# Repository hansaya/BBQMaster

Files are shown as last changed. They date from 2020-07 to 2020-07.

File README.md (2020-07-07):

# BBQMaster
8 channel temperature monitor for barbecuing.

# Features
* 4 NTC thermistor channels.
* 4 K-type thermocouple channels.
* Web interface to monitor the temperatures.
* MQTT support with hassio auto discovery.
* OTA updates.
* Web portal.
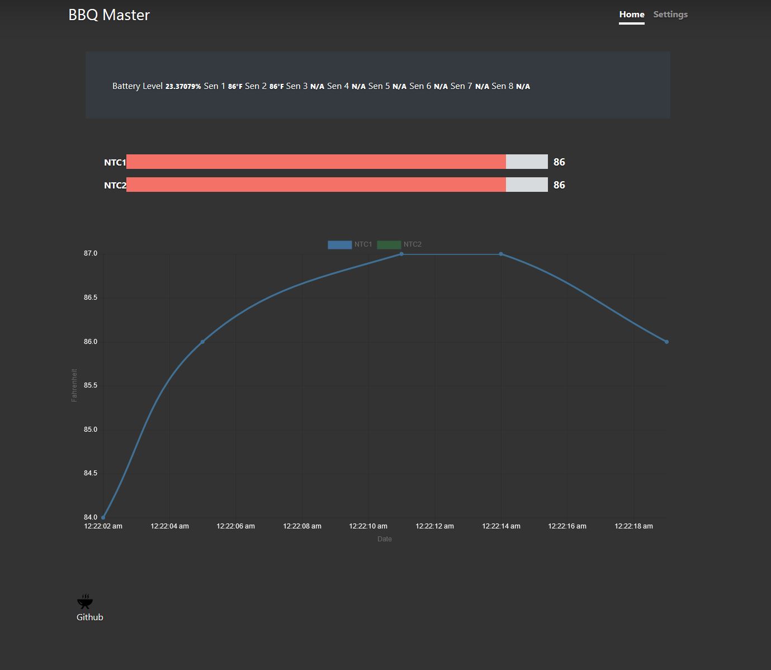
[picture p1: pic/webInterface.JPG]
Web Interface


# Background
I got into smoking meat last few years and figured out maintaining the temperature is a big part of getting juicy results. Like everyone else, I do not have patience to stay right next to the smoker to monitor the temps. Specially if you have a cheaper lower-end smoker; monitoring the temperature is crucial. The usual solution is to buy a wireless temp monitor out of Amazon so if you find one that works for you, go for it. My solution here is expensive, close to 100$. I ended up creating this project because I broke two sub 50$ sensors and a upgrade will cost around 100$. Hence I decided to make one knowing I can create one less than 100$ plus I had fun creating it.

I had few requirements.
1) Monitor temperature over a web interface or a app.
2) Wireless.
3) Enough probes to monitor every corner of a brisket.
4) Be able to monitor the inside of the smoker and maybe the fire box.

Knowing the requirements, I decided to go with
1) 4 NTC probe inputs since its easy to find commercial probes online.
2) 4 thermocouple inputs for higher temperature monitoring. Why? NTC probes cannot handle high heat. They will degrade really fast when you put them over 300F.
3) Use esp32 as the brain because its cheap and easy to program.

# How to order and build the board
Board files are in "boards/" folder. Design in Eagle and you can just drop the zip file located in baord/bbqsensor/cam/ into jlcpcb.com to get them made.

Board design:
* 100mmx54mm 2-layer board.
* Jelly bean parts are 603 or above.
* Uses CP2104 as the USB interface.
* Buck coveter based on TPS54331DR. This will allow 9v-24v input.
* Lipo charging based on MCP73831.
* 3v3 Regulator based on AP2112.
* Thermocouple input handled by OneWire MAX3185.
* NTC thermistors are monitored by ADS1115 ADC for better accuracy.
* ESP32 as the brain.
* Terminal block connectors for easy connections.

For the bom, look at the schematic.

DISCLAIMER:
I'm a amature designer. I would recommend going over the schematic before ordering.
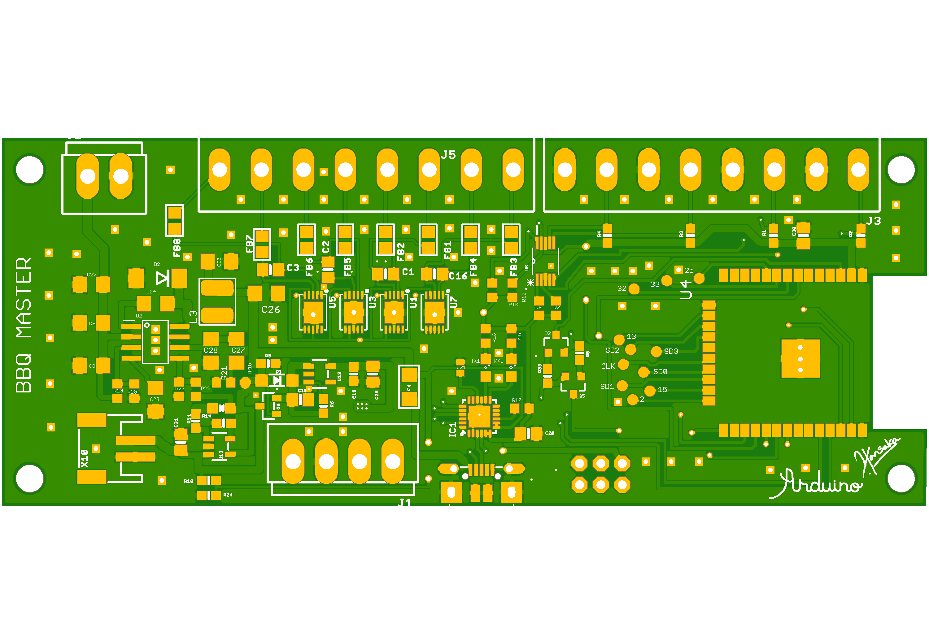
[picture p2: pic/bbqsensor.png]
Top side of the board

Completed board
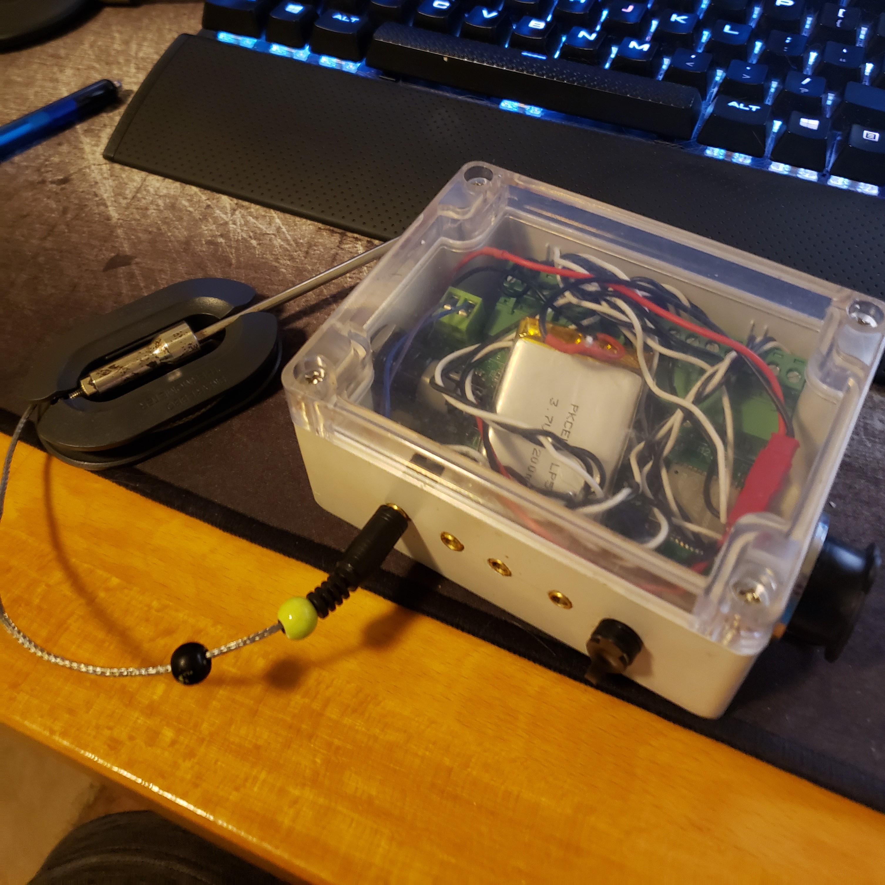
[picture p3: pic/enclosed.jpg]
Enclosure


## Probes

### NTC
Most common replacement bbq probes will work. I bought https://www.ebay.com/itm/Chugod-Grilling-BBQ-Meat-Thermometer-Probe-Replacement-Temperature-Probes-4-Pa/402310429902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

### K-type
You can buy any shape or size you want. However it is very hard to find probes designed for food. I would recommend use the thermocouple probes just to measure the inside temperature or firebox temperature.

# How to compile.
1) Download and install vscode with platformio. https://platformio.org/
2) Modify the platformio.ini file to either use serial port or use over the air updates.
3) If you are using Windows to compile, you might run into an compiler error because of Timelib. There are two headers named time.h in esp32 core and Time.h in Arduino timelib. These two looks the same to the compiler in windows because windows file names are case insensitive. Solution is to delete .pio/libdeps/myenv/Time/Time.h. More info https://github.com/esp8266/Arduino/issues/2341
4) Press upload.
5) Upload SPIFF image by running the vscode task "Upload File System Image". You can get to the task list from the left platformio panel or by typing "CTRL+SHIFT+P->Run task->platformio->Upload file system image".

# How to configure.
Firmware needs to know the MQTT server configuration. This can be done using WIFI manager portal. 
When you upload the code, if there is no previous credentials saved in the memory, WIFI AP will starts to broadcast using the name BBQ_Master. Connect to it and use the web portal to enter in the WIFI info as well as MQTT server address and the port. This creates a file in SPIFF called config.json. If you failed to enter the correct information or wants to modify the configuration later, create a file name config.json with data/ folder then use the "Upload file system Image" task to push the new file out.
config.json should looks like:
``
{"mqtt_server":"example.com", "mqtt_port":"1883"}
``

## Home Assistant
Turn on MQTT auto discovery https://www.home-assistant.io/docs/mqtt/discovery/. If esp32 connected to the MQTT server then hassio will automatically discover the device. If you are using non default discovery_prefix within hassio then change MQTT_HOME_ASSISTANT_DISCOVERY_PREFIX within the code reflect it.
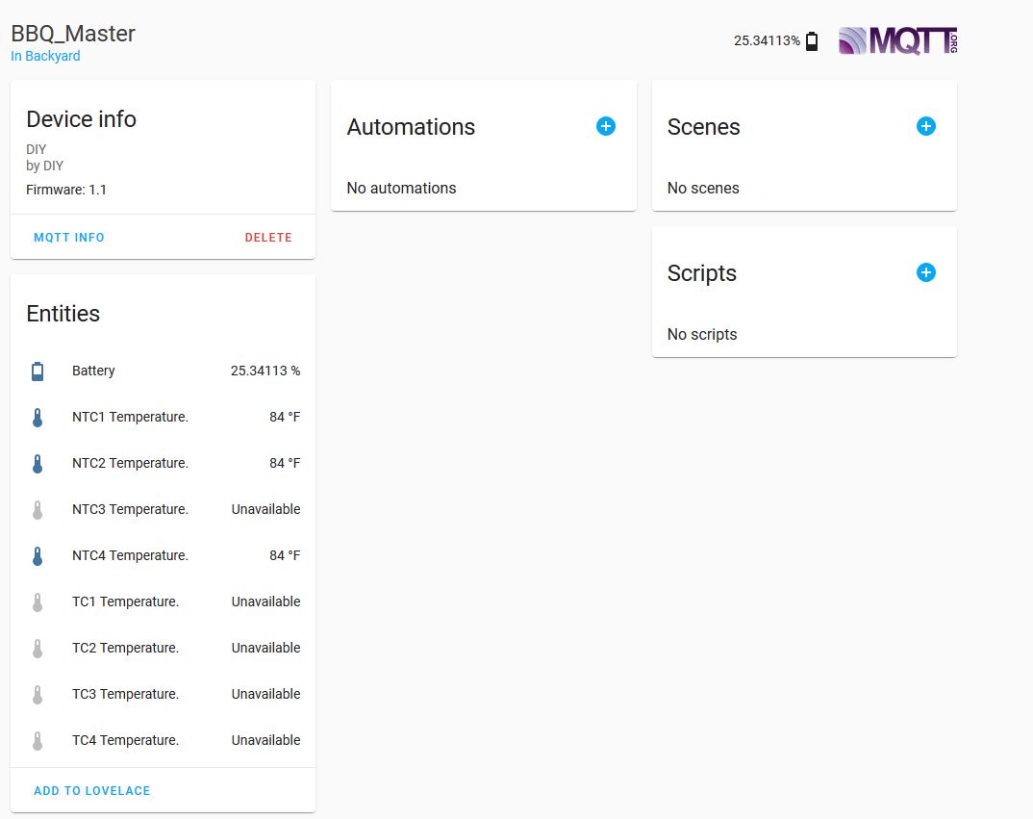
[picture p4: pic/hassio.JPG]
Hassio Device


# Known issues
* Forgot to add a LED indicator to the board.
* There is no way to turn off. As a workaround I attached a switch in series with the battery.
* Pubsub library only let you add a one "will" message. Because of this hassio sometimes fails to put all temperature sensor into unavailable state when disconnecting power from the device.
* Web interface theme functionality is broken.

# Todo
* Clean up the web interface.
* Add the ability to configure the temperature probe names through the web interface.
* Ability to calibrate the temperature probes using the web interface.
* Add a proper gauge to the battery indicator in the web interface.

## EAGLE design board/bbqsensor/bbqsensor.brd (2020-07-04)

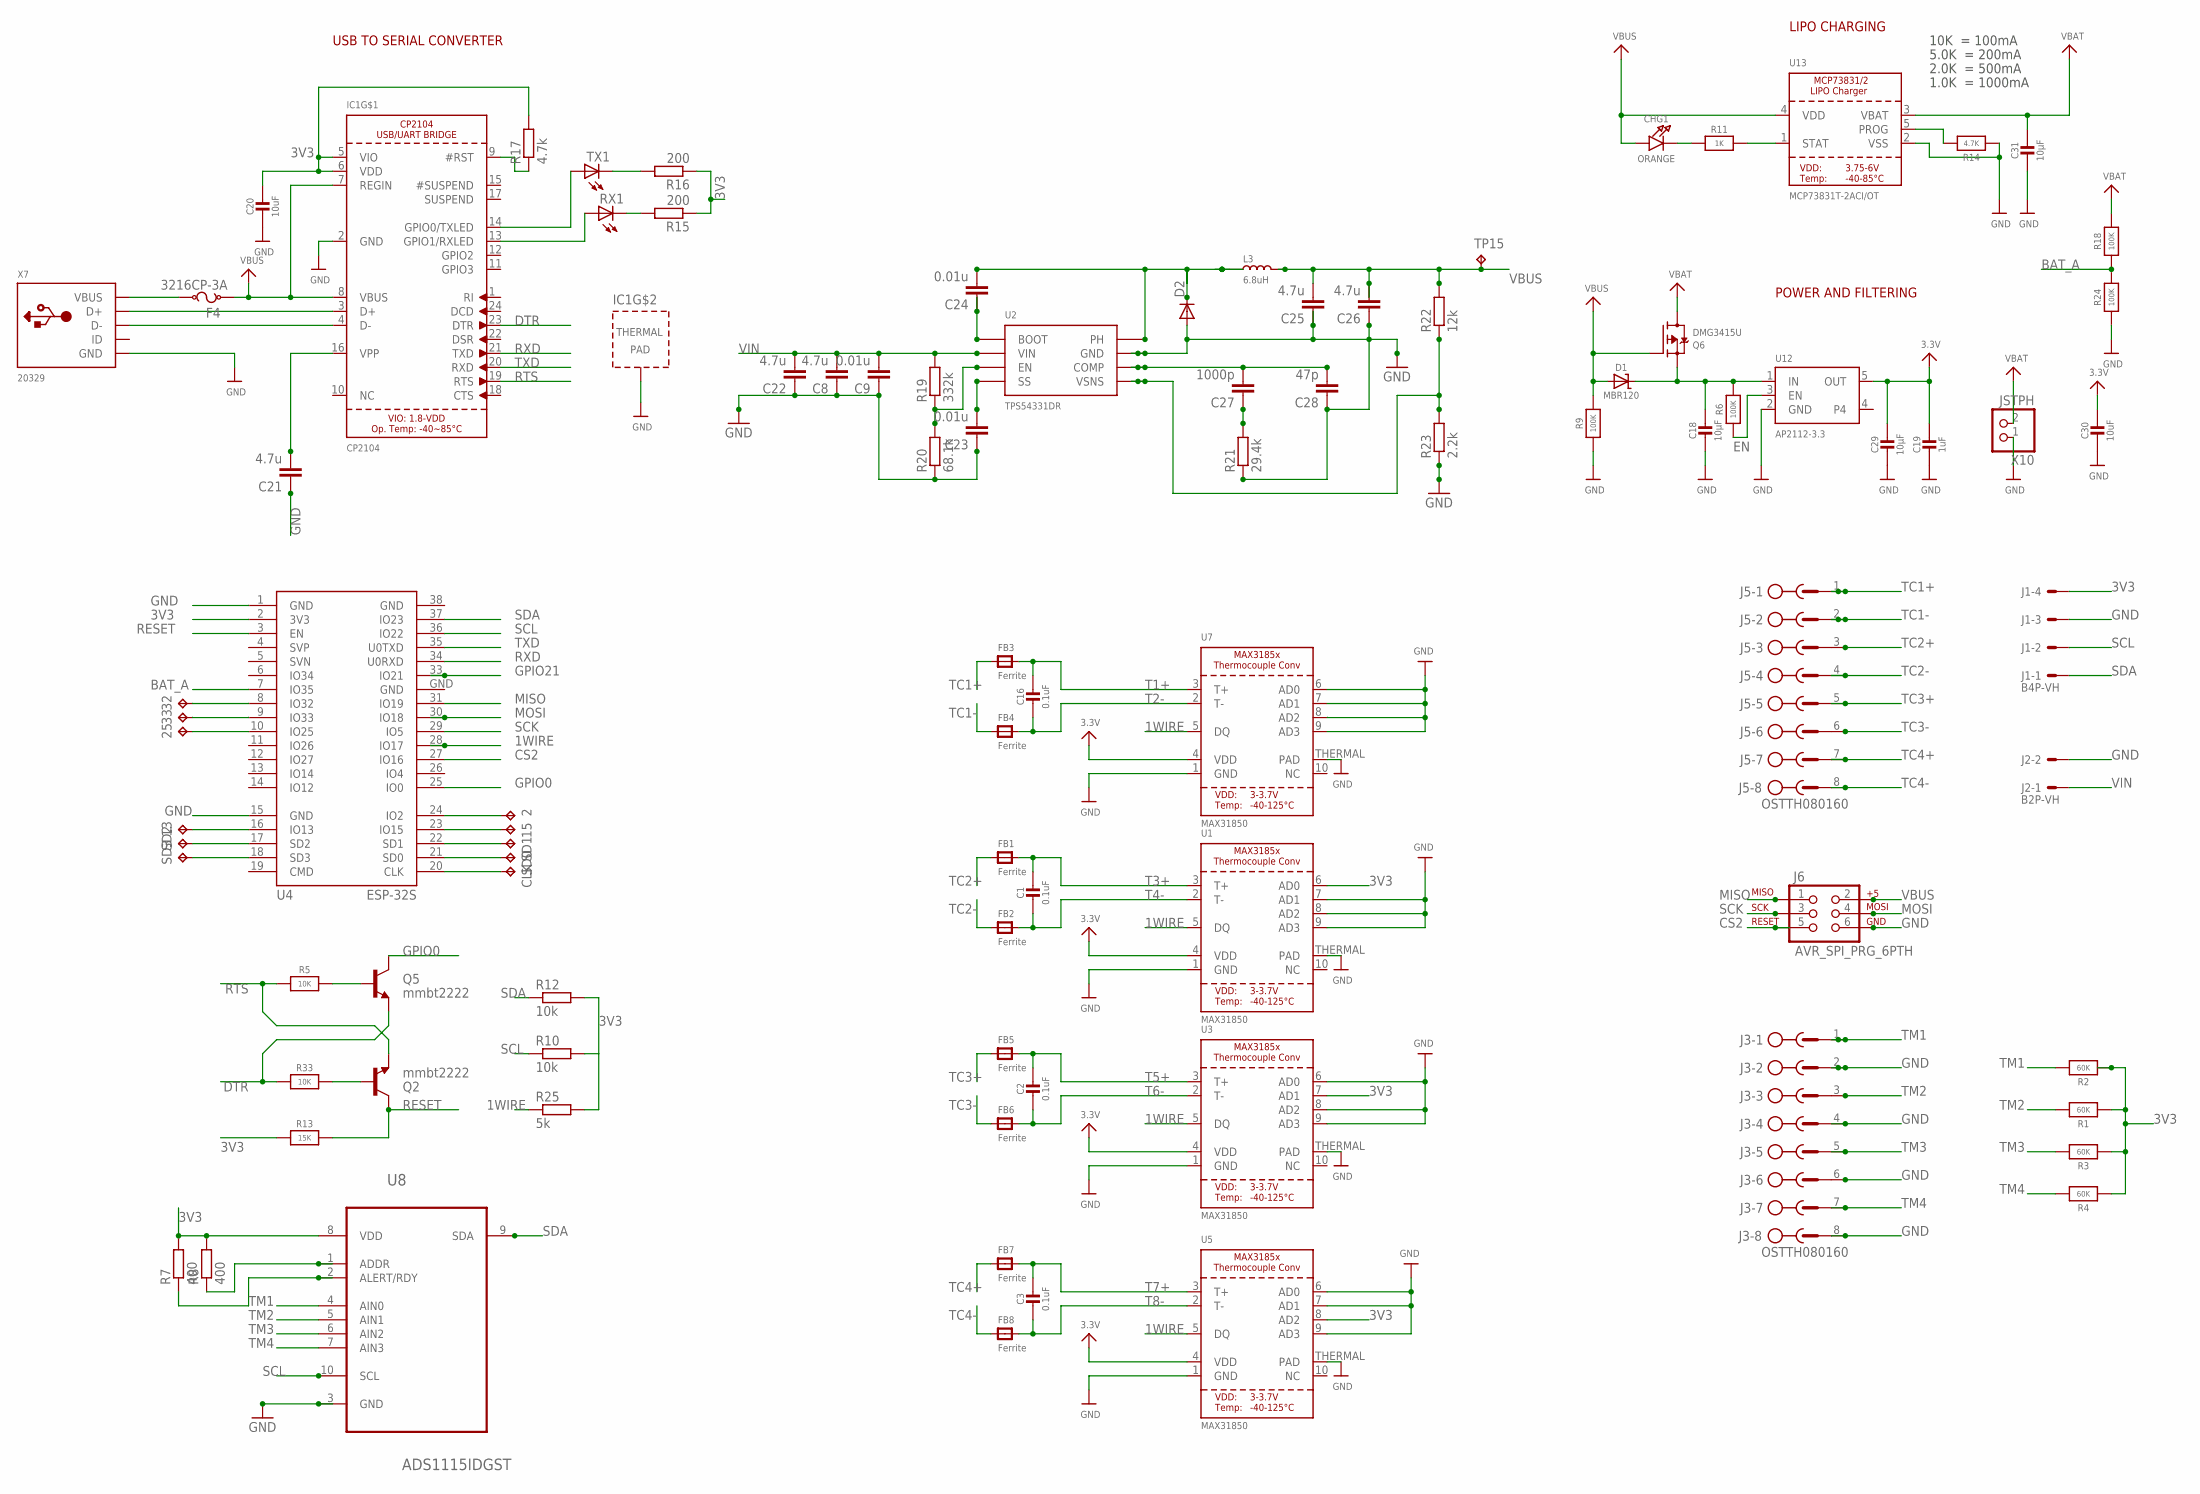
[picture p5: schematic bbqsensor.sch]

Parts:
2, 13, 15, 25, 32, 33: TPB1,27; B1,27
C1, C2, C3, C16: 0.1uF; 0805-NO
C8, C22, C25, C26: 4.7u; C1206
C9, C23, C24: 0.01u; C1206
C18, C29, C31: 10µF; 0805-NO
C19: 1uF; 0603-NO
C20, C30: 10uF; 0805-NO
C21: 4.7u; C1005
C27: 1000p; C1206
C28: 47p; C1206
CHG1: ORANGE; CHIPLED_0805_NOOUTLINE
CLK: TPB1,27; B1,27
D1: MBR120; SOD-123
D2: DIODE-DO214AA; DO214AA
F4: 3216CP-3A
FB1, FB2, FB3, FB4, FB5, FB6, FB7, FB8: Ferrite; 0805
IC1: CP2104; QFN24_4MM_SMSC
J1: B4P-VH; B4P
J2: B2P-VH; B2P
J3, J5: OSTTH080160; EDSTL130-08
J6: AVR_SPI_PRG_6PTH; 2X3
L3: 6.8uH; L1813
Q2, Q5: mmbt2222; SOT23-3
Q6: DMG3415U; SOT23-R
R1, R2, R3, R4: 60K; 0603-NO
R5, R33: 10K; 0603-NO
R6, R9, R18, R24: 100K; 0603-NO
R7, R8: 400; R0603
R10, R12: 10k; R0603
R11: 1K; 0603-NO
R13: 15K; 0603-NO
R14: 4.7K; 0603-NO
R15, R16: 200; R0603
R17: 4.7k; R0603
R19: 332k; R0603
R20: 68.1k; R0603
R21: 29.4k; R0603
R22: 12k; R0603
R23: 2.2k; R0603
R25: 5k; R0603
RX1: LEDSML0805; SML0805
SD0, SD1, SD2, SD3: TPB1,27; B1,27
TP15: TPB1,27; B1,27
TX1: LEDSML0805; SML0805
U1, U3, U5, U7: MAX31850; TDFN10_3X4MM
U2: TPS54331DR; SOIC-8
U4: ESP-32S
U8: ADS1115IDGST; SOP50P490X110-10N
U12: AP2112-3.3; SOT23-5
U13: MCP73831T-2ACI/OT; SOT23-5
X7: 20329; 4UCONN_20329_V2
X10: JSTPH; JSTPH2

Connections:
1WIRE: R25.1, U1.5 (DQ), U3.5 (DQ), U4.28 (IO17), U5.5 (DQ), U7.5 (DQ)
3V3: C19.1, C20.1, C29.1, C30.1, IC1.5 (VIO), IC1.6 (VDD), J1.4, R1.1, R2.1, R3.1, R4.1, R7.2, R8.2, R10.2, R12.2, R13.1, R15.1, R16.1, R17.2, R25.2, U1.4 (VDD), U1.6 (AD0), U3.4 (VDD), U3.7 (AD1), U4.2 (3V3), U5.4 (VDD), U5.8 (AD2), U7.4 (VDD), U8.8 (VDD), U12.5 (OUT)
BAT_A: R18.1, R24.2, U4.7 (IO35)
CS2: J6.5, U4.27 (IO16)
DTR: IC1.23 (DTR), Q5.2 (E), R33.1
EN: R6.1, U12.3 (EN)
GND: C8.1, C9.1, C18.2, C19.2, C20.2, C21.1, C22.1, C23.1, C25.1, C26.1, C28.1, C29.2, C30.2, C31.2, D2.A, IC1.2 (GND), IC1.THERM (TP), J1.3, J2.2, J3.2, J3.4, J3.6, J3.8, J6.6, R9.1, R14.1, R20.1, R21.1, R23.1, R24.1, U1.1 (GND), U1.7 (AD1), U1.8 (AD2), U1.9 (AD3), U1.THERMAL (PAD), U2.7 (GND), U3.1 (GND), U3.6 (AD0), U3.8 (AD2), U3.9 (AD3), U3.THERMAL (PAD), U4.1 (GND), U4.15 (GND), U4.38 (GND), U4.GND, U5.1 (GND), U5.6 (AD0), U5.7 (AD1), U5.9 (AD3), U5.THERMAL (PAD), U7.1 (GND), U7.6 (AD0), U7.7 (AD1), U7.8 (AD2), U7.9 (AD3), U7.THERMAL (PAD), U8.3 (GND), U12.2 (GND), U13.2 (VSS), X7.BASE@1 (GND), X7.BASE@2 (GND), X7.GND, X7.SPRT@1 (GND), X7.SPRT@2 (GND), X7.SPRT@3 (GND), X7.SPRT@4 (GND), X10.1
GPIO0: Q5.3 (C), U4.25 (IO0)
GPIO21: U4.33 (IO21)
MISO: J6.1, U4.31 (IO19)
MOSI: J6.4, U4.30 (IO18)
unnamed: 32.TP, U4.8 (IO32)
unnamed: 33.TP, U4.9 (IO33)
unnamed: 25.TP, U4.10 (IO25)
unnamed: 2.TP, U4.24 (IO2)
unnamed: 15.TP, U4.23 (IO15)
unnamed: 13.TP, U4.16 (IO13)
unnamed: SD1.TP, U4.22 (SD1)
unnamed: SD0.TP, U4.21 (SD0)
unnamed: CLK.TP, U4.20 (CLK)
unnamed: SD3.TP, U4.18 (SD3)
unnamed: SD2.TP, U4.17 (SD2)
unnamed: R7.1, U8.2 (ALERT/RDY)
unnamed: R8.1, U8.1 (ADDR)
unnamed: IC1.3 (D+), X7.D+
unnamed: IC1.4 (D-), X7.D-
unnamed: IC1.13 (GPIO1/RXLED), RX1.A
unnamed: R15.2, RX1.C
unnamed: R16.2, TX1.C
unnamed: IC1.14 (GPIO0/TXLED), TX1.A
unnamed: C18.1, D1.C, Q6.2 (S), R6.2, U12.1 (IN)
unnamed: CHG1.C, R11.1
unnamed: R11.2, U13.1 (STAT)
unnamed: R14.2, U13.5 (PROG)
unnamed: C21.2, IC1.16 (VPP)
unnamed: IC1.9 (#RST), R17.1
unnamed: F4.2, X7.VBUS
unnamed: Q2.1 (B), R33.2
unnamed: Q5.1 (B), R5.2
unnamed: C23.2, U2.4 (SS)
unnamed: R19.1, R20.2, U2.3 (EN)
unnamed: C24.1, U2.1 (BOOT)
unnamed: C24.2, D2.C, L3.1, U2.8 (PH)
unnamed: C27.2, C28.2, U2.6 (COMP)
unnamed: C27.1, R21.2
unnamed: R22.1, R23.2, U2.5 (VSNS)
RESET: Q2.3 (C), R13.2, U4.3 (EN)
RTS: IC1.19 (RTS), Q2.2 (E), R5.1
RXD: IC1.21 (TXD), U4.34 (U0RXD)
SCK: J6.3, U4.29 (IO5)
SCL: J1.2, R10.1, U4.36 (IO22), U8.10 (SCL)
SDA: J1.1, R12.1, U4.37 (IO23), U8.9 (SDA)
T1+: C16.1, FB3.2, U7.3 (T+)
T2-: C16.2, FB4.2, U7.2 (T-)
T3+: C1.1, FB1.2, U1.3 (T+)
T4-: C1.2, FB2.2, U1.2 (T-)
T5+: C2.1, FB5.2, U3.3 (T+)
T6-: C2.2, FB6.2, U3.2 (T-)
T7+: C3.1, FB7.2, U5.3 (T+)
T8-: C3.2, FB8.2, U5.2 (T-)
TC1+: FB3.1, J5.1
TC1-: FB4.1, J5.2
TC2+: FB1.1, J5.3
TC2-: FB2.1, J5.4
TC3+: FB5.1, J5.5
TC3-: FB6.1, J5.6
TC4+: FB7.1, J5.7
TC4-: FB8.1, J5.8
TM1: J3.1, R2.2, U8.4 (AIN0)
TM2: J3.3, R1.2, U8.5 (AIN1)
TM3: J3.5, R3.2, U8.6 (AIN2)
TM4: J3.7, R4.2, U8.7 (AIN3)
TXD: IC1.20 (RXD), U4.35 (U0TXD)
VBAT: C31.1, Q6.3 (D), R18.2, U13.3 (VBAT), X10.2
VBUS: C25.2, C26.2, CHG1.A, D1.A, F4.1, IC1.7 (REGIN), IC1.8 (VBUS), J6.2, L3.2, Q6.1 (G), R9.2, R22.2, TP15.TP, U13.4 (VDD)
VIN: C8.2, C9.2, C22.2, J2.1, R19.2, U2.2 (VIN)

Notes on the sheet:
USB TO SERIAL CONVERTER
POWER AND FILTERING
10K = 100mA
5.0K = 200mA
2.0K = 500mA
1.0K = 1000mA
LIPO CHARGING

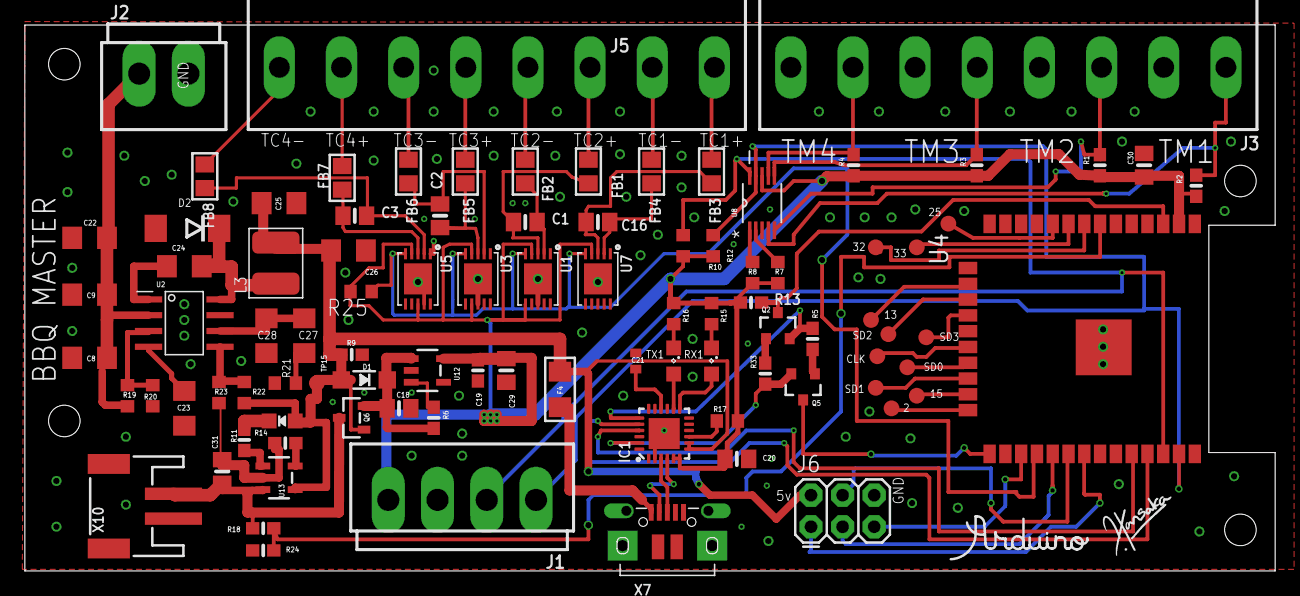
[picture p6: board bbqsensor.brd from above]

Board: 2 copper layers, 100.6 x 43.9 mm, 95 parts (0 on the bottom side), 75 nets.

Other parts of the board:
U$5: SIGNATURE
U$6: LOGO-A

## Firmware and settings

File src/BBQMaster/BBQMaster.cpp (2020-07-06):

#include <FS.h>
#include <SPIFFS.h>
#include <Adafruit_ADS1015.h>
#include <DNSServer.h>
#include <OneWire.h>
#include <WiFi.h>
#include <AsyncTCP.h>
#include <ESPAsyncWebServer.h>
#include <ESPAsyncWiFiManager.h>
#include <Wire.h>
#include <ArduinoJson.h>
#include <SimpleList.h>
#include <DallasTemperature.h>
#include <ArduinoOTA.h>
#include <NtpClientLib.h>
#include <PubSubClient.h>

// #define DEBUG_SERIAL
// #define DEBUG_TELNET
// #define DEBUG_EXTRA_OUTPUT

// Macros for debugging
#ifdef DEBUG_TELNET
   #define     DEBUG_TELNET_PORT 23
   WiFiServer  telnetServer(DEBUG_TELNET_PORT);
   WiFiClient  telnetClient;
   #define     DEBUG_PRINT(x)    telnetClient.print(x)
   #define     DEBUG_PRINT_WITH_FMT(x, fmt)    telnetClient.printf(x, fmt)
   #define     DEBUG_PRINTLN(x)  telnetClient.println(x)
   #define     DEBUG_PRINTLN_WITH_FMT(x, fmt)  telnetClient.println(x, fmt)
#elif defined(DEBUG_SERIAL)
   #define     DEBUG_PRINT(x)    Serial.print(x)
   #define     DEBUG_PRINT_WITH_FMT(x, fmt)    Serial.printf(x, fmt)
   #define     DEBUG_PRINTLN(x)  Serial.println(x)
   #define     DEBUG_PRINTLN_WITH_FMT(x, fmt)  Serial.println(x, fmt)
#else
   #define     DEBUG_PRINT(x)
   #define     DEBUG_PRINT_WITH_FMT(x, fmt)
   #define     DEBUG_PRINTLN(x)
   #define     DEBUG_PRINTLN_WITH_FMT(x, fmt)
#endif

#define I2C_SDA_PIN 23
#define I2C_SCL_PIN 22
#define BATTERY_V_PIN 35

#define BAT_RATIO 0.0017240449438202
#define NTC_MAX_ADC 27550.00
#define NTC_REF_RES 62000
#define NTC_SMP_TMP 25.81
#define NTC_SMP_RES 52250
#define NTC_BCOEFFICIENT 4200 //3950
#define HIST_SIZE 20
#define HIST_INT 5000
#define SENSOR_READ_INT 1500
#define MQTT_PUBLISH_PERIOD 10000

Adafruit_ADS1115 g_ads (0x49); /* Use this for the 16-bit version */
AsyncWebServer g_server (80);
OneWire g_oneWireTemp (17);
DallasTemperature g_thermoCouples (&g_oneWireTemp);
DNSServer dns;

// MAX31850KATB+-ND sensors
DeviceAddress g_sensor1 = {0x3B, 0x45, 0x21, 0x18, 0x00, 0x00, 0x00, 0x2D};
DeviceAddress g_sensor2 = {0x3B, 0xF1, 0x22, 0x18, 0x00, 0x00, 0x00, 0xB8};
DeviceAddress g_sensor3 = {0x3B, 0xF3, 0x22, 0x18, 0x00, 0x00, 0x00, 0xD6};
DeviceAddress g_sensor4 = {0x3B, 0x43, 0x21, 0x18, 0x00, 0x00, 0x00, 0x9F};

double g_batteryVoltage = 0;
double g_batteryLevel = 0;
short g_maxWorkingSensors = 0;
bool firmwareUpdating = false;
bool g_shouldSaveConfig = false;

// Host name of the device.
const char* g_hostName= "BBQ_Master";

// MQTT stuff
WiFiClient g_espClient;
PubSubClient g_mqttClient(g_espClient);

// MQTT configs
#define MQTT_HOME_ASSISTANT_DISCOVERY_PREFIX  "homeassistant"
char g_mqtt_server[40] = "example.com";
char g_mqtt_port[6] = "1883";
char g_topicMQTTHeader[22 + 11];
char g_uniqueId[5];

// Representation of one temperature probe
struct Sensor
{
   // Availability flag
   bool m_ind;
   // Temperature
   double m_tempF;
   // Name of the sensor
   String m_name;

public:
   Sensor (bool ind, double tempF, String name) : m_ind (ind), m_tempF (tempF), m_name (name) {}
   Sensor () : m_ind (false), m_tempF (0), m_name ("N/A") {}
};

// Data point completed with multiple probes
struct DataPoint
{
   int m_time;
   Sensor m_sensors[8];
};

// Current data set
DataPoint g_lastSenUpdate;

// Saving the history for the histogram
SimpleList<DataPoint> g_tempHist;

// Handle telnet debuging
#if defined(DEBUG_TELNET)
void handleTelnet(void) {
  if (telnetServer.hasClient()) {
    if (!telnetClient || !telnetClient.connected()) {
      if (telnetClient) {
        telnetClient.stop();
      }
      telnetClient = telnetServer.available();
    } else {
      telnetServer.available().stop();
    }
  }
}
#endif

// Setup OTA
void setupOTA(const char *hostname)
{
  // Config OTA updates
  ArduinoOTA.onStart([]() { DEBUG_PRINTLN("Start. Disbling regular work!"); firmwareUpdating=true;});
  ArduinoOTA.onEnd([]() { DEBUG_PRINTLN("\nEnd"); firmwareUpdating = false;});
  ArduinoOTA.onProgress([](unsigned int progress, unsigned int total) { DEBUG_PRINT_WITH_FMT("Progress: %u%%\r", (progress / (total / 100))); });
  ArduinoOTA.onError([](ota_error_t error) {
    DEBUG_PRINT_WITH_FMT("Error[%u]: ", error);
    if (error == OTA_AUTH_ERROR) DEBUG_PRINTLN("Auth Failed");
    else if (error == OTA_BEGIN_ERROR) DEBUG_PRINTLN("Begin Failed");
    else if (error == OTA_CONNECT_ERROR) DEBUG_PRINTLN("Connect Failed");
    else if (error == OTA_RECEIVE_ERROR) DEBUG_PRINTLN("Receive Failed");
    else if (error == OTA_END_ERROR) DEBUG_PRINTLN("End Failed");
    firmwareUpdating = false;
  });
  ArduinoOTA.setHostname(hostname);
  ArduinoOTA.begin();  
}

// Saving the config to SPIFF
void saveConfig () {
  DynamicJsonDocument json (256);
  json["mqtt_server"] = g_mqtt_server;
  json["mqtt_port"] = g_mqtt_port;

  File configFile = SPIFFS.open("/config.json", "w");
  if (!configFile) {
    DEBUG_PRINTLN("failed to open config file for writing");
  }
  serializeJson(json, configFile);
  configFile.close();
}

// Reading the config from SPIFF
void readConfig ()
{
  if (SPIFFS.begin()) {
      DEBUG_PRINTLN("SPIFFS started");
      if (SPIFFS.exists("/config.json")) {
         //file exists, reading and loading
         DEBUG_PRINTLN("reading config file");
         File configFile = SPIFFS.open("/config.json", "r");
         if (configFile) {
            DEBUG_PRINTLN("opened config file");
            size_t size = configFile.size();
            // Allocate a buffer to store contents of the file.
            std::unique_ptr<char[]> buf(new char[size]);

            configFile.readBytes(buf.get(), size);
            DynamicJsonDocument json (size+1);
            DeserializationError error = deserializeJson(json, buf.get());
            if (!error) {
               DEBUG_PRINT("parsed json config: ");
               serializeJson(json, Serial);
               DEBUG_PRINTLN();
               strcpy(g_mqtt_server, json["mqtt_server"]);
               strcpy(g_mqtt_port, json["mqtt_port"]);

            } else {
               DEBUG_PRINTLN("failed to load json config");
               saveConfig ();
            }
         }
      }
      else
         saveConfig ();
  } else {
      DEBUG_PRINTLN("Formatting the flash...");
      SPIFFS.format();
      DEBUG_PRINTLN("SPIFFS Mount failed");
  }
}

// Manages wifi portal
void manageWifi (bool reset_config = false)
{
  // The extra parameters to be configured (can be either global or just in the setup)
  AsyncWiFiManagerParameter custom_mqtt_server("server", "MQTT server", g_mqtt_server, 39);
  AsyncWiFiManagerParameter custom_mqtt_port("port", "MQTT port", g_mqtt_port, 5);

  AsyncWiFiManager wifiManager(&g_server, &dns);
  wifiManager.setConnectTimeout(60);
  wifiManager.setConfigPortalTimeout(60);
  wifiManager.setMinimumSignalQuality(10);
  wifiManager.addParameter(&custom_mqtt_server);
  wifiManager.addParameter(&custom_mqtt_port);
  wifiManager.setSaveConfigCallback([](){
     g_shouldSaveConfig = true;
  });
  
  if (reset_config)
    wifiManager.startConfigPortal(g_hostName);
  else
    wifiManager.autoConnect(g_hostName); // This will hold the connection till it get a connection

  if (g_shouldSaveConfig)
  {
      strncpy(g_mqtt_server, custom_mqtt_server.getValue(), 39);
      strncpy(g_mqtt_port, custom_mqtt_port.getValue(), 5);
      saveConfig ();
      g_shouldSaveConfig = false;
  }
}

// Calculate NTC temp using steinhart equation
float calculateNTCTemp (int16_t adcValue)
{
  if (adcValue < NTC_MAX_ADC)
  {
    float steinhart;
    // Resistance calculation
    steinhart = (NTC_MAX_ADC / adcValue) - 1;
    steinhart = NTC_REF_RES / steinhart;

    // Rest of the steinhart equation
    steinhart = steinhart / NTC_SMP_RES;
    steinhart = log(steinhart);                  // ln(R/Ro)
    steinhart /= NTC_BCOEFFICIENT;                   // 1/B * ln(R/Ro)
    steinhart += 1.0 / (NTC_SMP_TMP + 273.15); // + (1/To)
    steinhart = 1.0 / steinhart;                 // Invert
    steinhart -= 273.15;
    return DallasTemperature::toFahrenheit(steinhart);
  }
  else
    return 0.0;
}

// Check whether temperature is valid.
bool isValidTemp (float temp)
{
   if (temp <= 32.0 || temp > 1000.00)
      return false;
   else
      return true;
}

// Battery precentage calculator
float batteryLevel()
{
   g_batteryVoltage = analogRead (BATTERY_V_PIN) * BAT_RATIO;

   float output = 0.0;             //output value
   const float battery_max = 4.20; //maximum voltage of battery
   const float battery_min = 3.5;  //minimum voltage of battery before shutdown

   output = ((g_batteryVoltage - battery_min) / (battery_max - battery_min)) * 100;
   if (output < 100)
      return output;
   else
      return 100.0f;
}


// Read all the sensors
void readSensors ()
{
   int16_t adc0, adc1, adc2, adc3;
   float ntc0, ntc1, ntc2, ntc3;
   // NTC readings
   adc0 = g_ads.readADC_SingleEnded (0);
   adc1 = g_ads.readADC_SingleEnded (1);
   adc2 = g_ads.readADC_SingleEnded (2);
   adc3 = g_ads.readADC_SingleEnded (3);

   ntc0 = calculateNTCTemp (adc0);
   ntc1 = calculateNTCTemp (adc1);
   ntc2 = calculateNTCTemp (adc2);
   ntc3 = calculateNTCTemp (adc3);

   float tcp0, tcp1, tcp2, tcp3;
   tcp0 = g_thermoCouples.getTempF (g_sensor1);
   tcp1 = g_thermoCouples.getTempF (g_sensor2);
   tcp2 = g_thermoCouples.getTempF (g_sensor3);
   tcp3 = g_thermoCouples.getTempF (g_sensor4);

   long int tps = now ();
   if (tps > 0)
   {
      g_lastSenUpdate.m_time = tps;
      g_lastSenUpdate.m_sensors[0] = Sensor (isValidTemp (ntc0), ntc0, "NTC1");
      g_lastSenUpdate.m_sensors[1] = Sensor (isValidTemp (ntc1), ntc1, "NTC2");
      g_lastSenUpdate.m_sensors[2] = Sensor (isValidTemp (ntc2), ntc2, "NTC3");
      g_lastSenUpdate.m_sensors[3] = Sensor (isValidTemp (ntc3), ntc3, "NTC4");

      // Thermocouple readings
      g_lastSenUpdate.m_sensors[4] = Sensor (isValidTemp (tcp0), tcp0, "TC1");
      g_lastSenUpdate.m_sensors[5] = Sensor (isValidTemp (tcp1), tcp1, "TC2");
      g_lastSenUpdate.m_sensors[6] = Sensor (isValidTemp (tcp2), tcp2, "TC3");
      g_lastSenUpdate.m_sensors[7] = Sensor (isValidTemp (tcp3), tcp3, "TC4");
   }

   g_batteryLevel = batteryLevel ();

   // Request thermo couple data
   g_thermoCouples.setWaitForConversion(false);  // makes it async
   g_thermoCouples.requestTemperatures();
   g_thermoCouples.setWaitForConversion(true);

#ifdef DEBUG_EXTRA_OUTPUT
   DEBUG_PRINT("AIN0: ");
   DEBUG_PRINTLN(adc0);

   DEBUG_PRINT("Temp NTC 0 F: ");
   DEBUG_PRINTLN(g_lastSenUpdate.m_sensors[0].m_tempF);
   DEBUG_PRINT("Temp NTC 1 F: ");
   DEBUG_PRINTLN(g_lastSenUpdate.m_sensors[1].m_tempF);
   DEBUG_PRINT("Temp NTC 2 F: ");
   DEBUG_PRINTLN(g_lastSenUpdate.m_sensors[2].m_tempF);
   DEBUG_PRINT("Temp NTC 3 F: ");
   DEBUG_PRINTLN(g_lastSenUpdate.m_sensors[3].m_tempF);

   DEBUG_PRINT("Temp 0 F: ");
   DEBUG_PRINTLN(tcp0);
   DEBUG_PRINT("Temp 1 F: ");
   DEBUG_PRINTLN(tcp1);
   DEBUG_PRINT("Temp 2 F: ");
   DEBUG_PRINTLN(tcp2);
   DEBUG_PRINT("Temp 3 F: ");
   DEBUG_PRINTLN(tcp3);

#endif
}

// Send the last sensor data reading in json format.
DynamicJsonDocument jsonSensorData ()
{
   DynamicJsonDocument json(1024);  // Current JSON static buffer
   json["bat"] = g_batteryLevel;
   json["t"] = g_lastSenUpdate.m_time;
   JsonArray sensors = json.createNestedArray ("sensors");

   for (int i = 0; i < 8; ++i)
   {
      JsonObject tempS = sensors.createNestedObject ();
      tempS["i"] = g_lastSenUpdate.m_sensors[i].m_ind;
      tempS["v"] = int(g_lastSenUpdate.m_sensors[i].m_tempF);
      tempS["n"] = g_lastSenUpdate.m_sensors[i].m_name;
   }

   return json;
}

// Send the last sensor data reading in json format.
void sendMeasures (AsyncWebServerRequest *request)
{
   char tempJson[1024];
   serializeJson(jsonSensorData (), tempJson);
   request->send (200, "application/json", tempJson);  // Send history data to the web client
}

// Send the history in JSON format.
void sendHistory (AsyncWebServerRequest *request)
{
   DEBUG_PRINTLN("Sending History");
   DynamicJsonDocument json(5560 + 100);  // Current JSON static buffer
   JsonArray hist = json.createNestedArray ("hist");

   for (SimpleList<DataPoint>::iterator it = g_tempHist.begin (); it != g_tempHist.end (); ++it)
   {
      JsonObject item = hist.createNestedObject ();
      item["t"] = it->m_time;
      JsonArray jsonSens = item.createNestedArray ("sensors");

      for (int i = 0; i < 8; i++)
      {
         if (it->m_sensors[i].m_ind)
         {
            JsonObject sensor = jsonSens.createNestedObject ();
            sensor["n"] = it->m_sensors[i].m_name;
            sensor["v"] = int(it->m_sensors[i].m_tempF);  // Lose the decimal places for space saving.
         }
      }
   }
   char tempJson[5560 + 100];
   serializeJson(json, tempJson); // Export JSON object as a String
   request->send (200, "application/json", tempJson);  // Send history data to the web client
}

// Add a data point to the history
void addDataPointToHistory ()
{
  short validSensors = 0;
  bool validData = false;
  for (int i = 0; i < 8; i++)
  {
     if (g_lastSenUpdate.m_sensors[i].m_ind)
     {
       validSensors++;
       validData = true;
     }
  }
  // Clear the history if the count does not match.
  if (g_maxWorkingSensors != validSensors)
  {
    g_tempHist.clear ();
    g_maxWorkingSensors = validSensors;
  }

  if (validData)
  {
   g_tempHist.push_back (g_lastSenUpdate);
   if (g_tempHist.size () > HIST_SIZE)
   {
      g_tempHist.erase (g_tempHist.begin ());
   }
  }

#ifdef DEBUG_EXTRA_OUTPUT
   DEBUG_PRINT ("size g_tempHist ");
   DEBUG_PRINTLN(g_tempHist.size ());
#endif
}

// Publish the MQTT payload.
void publishToMQTT(const char* p_topic,const char* p_payload) {
  if (g_mqttClient.publish(p_topic, p_payload, true)) {
    DEBUG_PRINT(F("INFO: MQTT message published successfully, topic: "));
    DEBUG_PRINT(p_topic);
    DEBUG_PRINT(F(", payload: "));
    DEBUG_PRINTLN(p_payload);
  } else {
    DEBUG_PRINTLN(F("ERROR: MQTT message not published, either connection lost, or message too large. Topic: "));
    DEBUG_PRINT(p_topic);
    DEBUG_PRINT(F(" , payload: "));
    DEBUG_PRINTLN(p_payload);
  }
}

// Function that publishes birthMessage
void publishAvailability() 
{
   char topicAvailability[22 + 11 + 10];
   snprintf(topicAvailability, 22 + 11 + 10, "%s/avail",g_topicMQTTHeader);
   g_mqttClient.publish(topicAvailability, "online", true);
}

// Function that publishes availability of each sensor
void publishSensorAvailability() 
{
   for (int i = 0; i < 8; i++)
   {
      char availabilitySensorTopic[22 + 11 + 20];
      snprintf(availabilitySensorTopic, 22 + 11 + 20, "%s/%s/avail", g_topicMQTTHeader, g_lastSenUpdate.m_sensors[i].m_name.c_str());
      if (g_lastSenUpdate.m_sensors[i].m_ind)
         publishToMQTT(availabilitySensorTopic, "online");
      else
         publishToMQTT(availabilitySensorTopic, "offline");
   }
}

// Publish MQTT discovery config to let hassio auto discover the sensors.
void publishDiscovery(void) 
{
   // Create json config for battery level.
   char uniqueId[15];
   snprintf(uniqueId, 15, "%sbat", g_uniqueId);
   char batDiscoverTopic[22 + 11 + 10];
   snprintf(batDiscoverTopic, 22 + 11 + 10, "%s/bat/config", g_topicMQTTHeader);

   StaticJsonDocument<500> root;
   root["~"] = g_topicMQTTHeader;
   root["dev_cla"] = "battery";
   root["uniq_id"] = uniqueId;
   root["name"] = "Battery";
   root["avty_t"] = "~/avail";
   root["stat_t"] = "~/state";
   root["unit_of_meas"] = "%";
   root["val_tpl"] = "{{value_json.bat}}";
   root["device"]["ids"] = g_uniqueId;
   root["device"]["name"] = g_hostName;
   root["device"]["mf"] = "DIY";
   root["device"]["mdl"] = "DIY";
   root["device"]["sw"] = "1.1";
   char outgoingJsonBuffer[500];
   serializeJson(root, outgoingJsonBuffer);
   publishToMQTT(batDiscoverTopic, outgoingJsonBuffer);

   // Create json config for each sensor.
   for (int i = 0; i < 8; i++)
   {
      char sensorConfigTopic[22 + 11 + 20];
      snprintf(sensorConfigTopic, 22 + 11 + 20, "%s/%s/config", g_topicMQTTHeader, g_lastSenUpdate.m_sensors[i].m_name.c_str());
      char availabilitySensorTopic[15];
      snprintf(availabilitySensorTopic, 15, "~/%s/avail", g_lastSenUpdate.m_sensors[i].m_name.c_str());

      char sensorId[15];
      snprintf(sensorId, 15, "%s%s", g_uniqueId, g_lastSenUpdate.m_sensors[i].m_name.c_str());
      char sensorName[30];
      snprintf(sensorName, 30, "%s Temperature.", g_lastSenUpdate.m_sensors[i].m_name.c_str());
      String jsonTemplate = "{{value_json.sensors[" + String(i) + "].v}}";

      StaticJsonDocument<500> sensorRoot;
      sensorRoot["~"] = g_topicMQTTHeader;
      sensorRoot["dev_cla"] = "temperature";
      sensorRoot["uniq_id"] = sensorId;
      sensorRoot["name"] = sensorName;
      sensorRoot["avty_t"] = availabilitySensorTopic;
      sensorRoot["stat_t"] = "~/state";
      sensorRoot["unit_of_meas"] = "°F";
      sensorRoot["val_tpl"] = jsonTemplate;
      sensorRoot["exp_aft"] = MQTT_PUBLISH_PERIOD/1000 + 5; // Invalidate the data if there is no data for 15seconds.
      sensorRoot["device"]["ids"] = g_uniqueId;
      sensorRoot["device"]["name"] = g_hostName;
      sensorRoot["device"]["mf"] = "DIY";
      sensorRoot["device"]["mdl"] = "DIY";
      sensorRoot["device"]["sw"] = "1.1";

      char sensorDisBuffer[500];
      serializeJson(sensorRoot, sensorDisBuffer);
      publishToMQTT(sensorConfigTopic, sensorDisBuffer);
   }
}

// MQTT Connect.
void connectToMqtt() 
{
   DEBUG_PRINT("Connecting to MQTT with client id ");
   String clientId = "BBQMaster_";
   clientId += String(random(0xffff), HEX);
   DEBUG_PRINT(clientId);
   DEBUG_PRINTLN("...");
   char topicAvailability[22 + 11 + 10];
   snprintf(topicAvailability, 22 + 11 + 10, "%s/avail",g_topicMQTTHeader);

   // Attempt to connect
   if (g_mqttClient.connect(clientId.c_str(), "", "", topicAvailability, 0, true, "offline"))
   {
      publishAvailability();
      publishDiscovery();
   }
   else
   {
      DEBUG_PRINT("Failed to connect to MQTT! ");
      DEBUG_PRINT(g_mqttClient.state());
      DEBUG_PRINTLN(" Trying again in 60 seconds");
   }
}

// Publish MQTT states
void publishDataToMqtt()
{
   char topicState[22 + 11 + 10];
   snprintf(topicState, 22 + 11 + 10, "%s/state", g_topicMQTTHeader);

   char tempJson[1024];
   serializeJson(jsonSensorData (), tempJson);
   publishToMQTT (topicState, tempJson);
   publishSensorAvailability();
}
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
void loop (void)
{
   // handle the Telnet connection
#if defined(DEBUG_TELNET)
   handleTelnet();
#endif
   unsigned long currentMillis = millis ();  // Time now
   // Handle server requests
   ArduinoOTA.handle ();

   if (!firmwareUpdating)
   {
      // Connect to MQTT server
      if (!g_mqttClient.connected())
      {
         static unsigned long mqttConnectWaitPeriod;
         if (currentMillis - mqttConnectWaitPeriod >= 30000)
         {
            mqttConnectWaitPeriod = currentMillis;
            connectToMqtt ();
         }
      }   
      g_mqttClient.loop();

      // Add a point to the history over time.
      static unsigned long histPreviousMillis;
      if (currentMillis - histPreviousMillis > HIST_INT)
      {
         histPreviousMillis = currentMillis;
         addDataPointToHistory ();
      }

      // Read the sensor data.
      static unsigned long prevMilForInputRead;
      if (currentMillis - prevMilForInputRead >= SENSOR_READ_INT)
      {
         prevMilForInputRead = currentMillis;
         readSensors ();
      }

      // Send MQTT state.
      static unsigned long prevMilForMqttPublish;
      if (currentMillis - prevMilForMqttPublish >= MQTT_PUBLISH_PERIOD)
      {
         prevMilForMqttPublish = currentMillis;
         if (g_mqttClient.connected())
            publishDataToMqtt ();
      }
   }
}

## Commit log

2020-07-04 board files
    [bbqsensor.brd, bbqsensor.sch]
2020-07-07 More documentation
    [bbqsensor.sch]

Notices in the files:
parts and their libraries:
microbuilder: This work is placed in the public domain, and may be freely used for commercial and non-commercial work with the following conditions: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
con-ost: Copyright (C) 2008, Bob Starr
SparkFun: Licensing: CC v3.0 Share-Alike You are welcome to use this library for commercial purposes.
